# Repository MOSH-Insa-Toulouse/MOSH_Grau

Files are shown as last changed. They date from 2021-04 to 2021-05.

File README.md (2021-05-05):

# MOSH_Grau
# Projet capteur

## SOMMAIRE 
* 1 [Description du projet](#description)
* 2 [Shield](#paragraph2)
* 3 [Arduino](#paragraph3)
* 4 [APK](#paragraph4)  
* 5 [Banc de test](#paragraph5)
* 6 [Idées d'amélioration et de développement](#paragraph6)

   La plupart des iformations se trouvent dans la datasheet.

--------- 
## Description du projet 

Ce projet est réalisé dans le cadre de la formation en ingénierie physique de l'INSA Toulouse. Il vise à introduire le développement de technologies performantes, transportables et à moindre coût. 
Ce projet aborde de nombreuses notions : la physique des systèmes granulaires, l'électroniqe analogique, Arduino Uno, la réalisation d'un PCB, le développement d'APK, la conception d'un banc de test et la réalisation d'une datasheet.

*Objectif* : Développer une jauge de contrainte lowtech, carctérisée et documentée. 

*Description du capteur* : Le capteur est une feuille de papier sur laquelle est déposée une fine couche de graphite. Le graphite déposée peut être vu comme un film conducteur constitué de réseaux de percolation. La déformation du papier se répercute sur les réseaux de percolation et donc sur la conductivité du film de graphite. La déformation du papier est proportionnelle à la variation de conductivité du film de graphite[¹]. Afin d'avoir une mesure de meilleure qualité,et en raison des valeurs de résistance du capteur treès élevées, le signal est conditionné par un circuit analogique comprenant un amplificateur transimpédance et différents filtres. Un écran OLED piloté par un encodeur rotatoire permet d'étendre les fonctionnalités du capteur. Une application Android a également été développée pour faciliter l'utilisation du capteur, même si le capteur se suffit à lui même. L'application et le capteur communique via un module bluetooth. Le shield comprenant tous les composants électroniques s'enfiche sur une carte Arduino Uno.

*Livrables* : 

1. Shield : comprend un amplificateur transimpédance, différents étages de filtrage, un module bluetooth (HC-05), un écran OLED (SSD1306) et un encodeur rotatoire (KY-040). La résistance R2 peut être changée facilement afin d'adapter le gain de l'amplificateur en fonction de la résistance du capteur. 
2. Code Arduino : permet de piloter l'encodeur rotatoire et l'écran OLED. Un menu s'affiche à l'écran avec 3 fonctionnailités principales:
- choix de R2
- choix de l'affichage de différentes mesures en temps réel : soit la tension à la sortie de A0 (ADC sur 10 bits), soit la déformation longitudinale du capteur, ou bien la résistance du capteur. 
- Mesure de contrainte au niveau de la jauge de déformation en fonction du matériaux choisi.
- Calibration du capteur (sensibilité).

Gère les flux de données entre l'APK et le microcontrôleur via le module BT. Permet également d'effectuer les différents traitements de données, comme le calcul de la déformation longitudinale en fonction de la déflection ou encore le calcule de contrainte en fonction de la déformation et d'un certain matériau (module de Young). 

3. APK : Affichage en temps réel  de la tension à la sortie de A0 (ADC sur 10 bits) et tracé du graphe correspondant, affichage de la résistance du capteur, et affichage et modification de la valeur de R2. Un fonctionnalité permet de faire la moyenne des mesures sur 5 secondes. 

[¹]: https://www.nature.com/articles/srep03812

--------- 
## Banc de test 

### Description du banc de test ###

La solution choisie afin de tester et caractériser les capteurs est l'application d'une déflection en compression ou en traction. 

- Déflection en compression : on fixe le capteur au niveau de la partie la plus large, et on applique une déflection contrôlable et mesurable (par exemple avec une règle), perpendiculairement vers le haut (avec la couche de graphite sur la face supérieure du papier) et à l'extrèmité de la jauge pour qu'elle se replie sur elle-même. 
- Déflection en traction : idem qu'en compression mais avec une délection provoquée par une froce dirigée vers le bas (avec la couche de graphite sur la face supérieure du papier). Plus difficile à mettre en oeuvre pour des raisons pratiques, notamment pour mesurer la déflection correctement. On peut alors s'aider de poids que l'on suspend à l'extrémité de la jauge. 

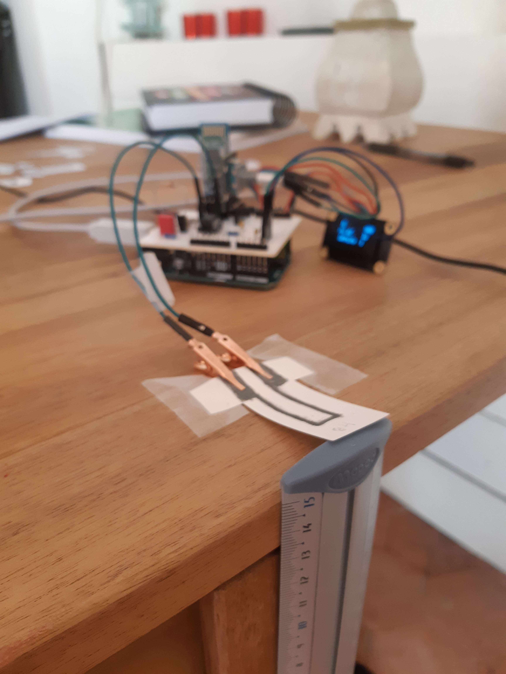
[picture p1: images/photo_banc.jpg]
 
 
 On mesure ainsi la variation de résistance relative en fonction de la déflection. En considérant notre capteur comme une poutre, avec de petites déformation nous pouvons alor remonter à la déformation logitudinale du capteur et calculer son facteur de jauge. Il est important que les prises de contact soient immobiles tout au long de la mesure pour ne pas fausser celle-ci. 
 Il faut également toucher le moins possible la couche de graphite du capteur pour ne pas biaiser les mesures.
 Pour effectuer nos mesures, noud avons moyenné chaque point sur 5 secondes à une fréquence dacquisition de 5Hz. L'incertitude de chaque mesure correspond à l'écart type de l'ensemble des échantillons correspondants à la mesure (voir APK).
 La défelction maximale appliquée est de 2 cm, au delà la déformation du capteur devient trop importante et il se peut que celui-ci se retrouve déformé de manière irréversible. 

**Paramètres étudiés :**

*Paramètres contrôlables :*

1. Type de papier : 
- Papier canson, 180 g/m², épaiseur : 0,21mm
- Feuille A4 de bureau standard, 80 g/m², épaisseur : 0,08mm,
- Fiche Bristol, 205 g/m², épaisseur : 0,22mm

2. Type de crayon : De 4H à 4B
3. Forme de la jauge, notamment la surface de la couche de graphite, la longueur du motif de graphite etc... 
4. Influence de la résistance nominale
5. Influence de R2

*Paramètres non contrôlables :*

1. Formation des réseaux de percolation
2. Epaisseur de la couche de graphite
3. Homogénéité de la couche de graphite

### Influence de R2 sur la mesure ###

La résistance R2 permet d'adapter le gain de l'amplificateur. Il permet notamment de déterminer la plage de résistance mesurable : 

###Idées d'amélioration et de développement 

- Réfléchir à un moyen de déposer le graphite de manière plus homogène
- Continuer à étudier les différents paramètre : dimensions de la jauge de graphite, dimensions du motif de graphite
- Réfléchir à une prise de contact plus appropriée, avec des électrodes fixes
- Continuer à prendre des mesures pour préciser ou réfuter la relation entre la résistance nominale et le facteur de jauge
- Faire les mesures en compression
- Automatiser le banc de test, en fixant tout simplement un fil au bout de la jauge, avec l'autre bout du fil accroché à un servomoteur. L'angle de rotation du servo-moteur est directement relié à la déflection de la jauge. 
- Optimiser le code de l'APK, et de l'Arduino, ajout de nouvelles fonctionnalités

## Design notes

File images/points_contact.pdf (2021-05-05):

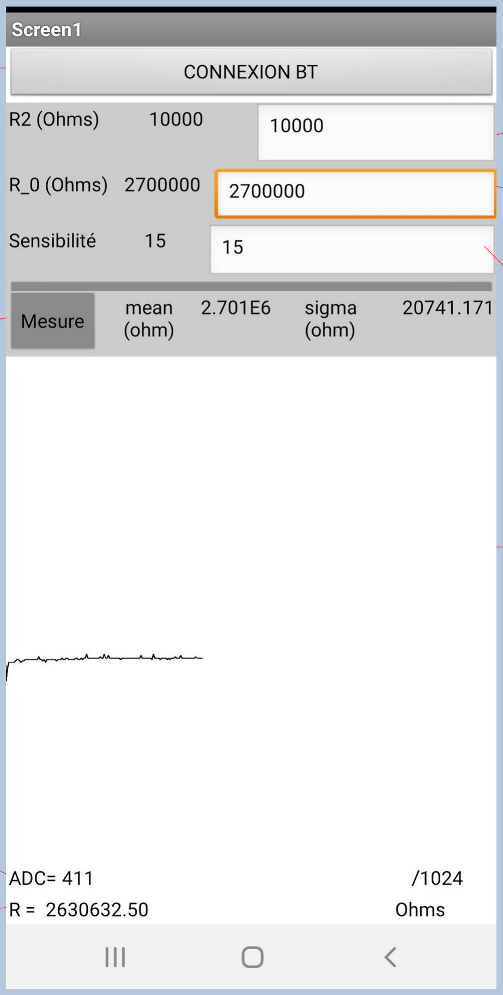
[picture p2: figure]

Bouton permettant
de se connecter au
module Bluetooth

Affichage en temps
réel de la valeur de
la résistance du
capteur en ohm.

Affichage en temps
réel de la valeur de
la tension en ADC
(sur 10 bits) à la
sortie du
conditionneur.

Faire une mesure
sur 5 secondes, la
moyenne et l’écarttype sont ensuite
calculés et
affichés .

Saisie de la
résistance de
calibration du
conditionneur en
ohm.

Saisie de la
résistance
nominale du
capteur en ohm.
Cette valeur peut
être mesurée avec
le bouton
« Mesure » .

Sensibilité du
capteur (Facteur
de jauge)

Tracé en temps
réel de l’évolution
de la tension (ADC)
à la sortie du
conditionneur en
fonction du temps.

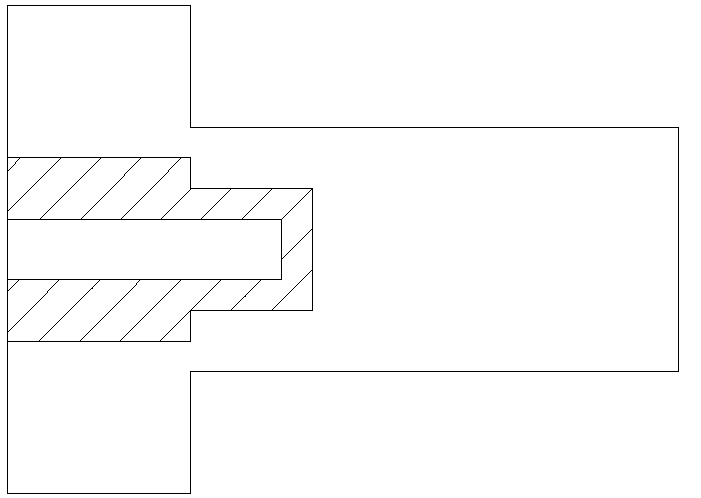
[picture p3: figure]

12

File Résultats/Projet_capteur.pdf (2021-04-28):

# Projet capteur

### victor.grau93

## April 2021

# 1 Introduction

Rapport et résultats projet capteur INSA 4GP

# 2 Inuence de la résistance de calibration (R2)

La résistance R2 permet d’adapter le gain de l’amplicateur. De plus, elle détermine la plage de résistance mesurable :

# valR = (1 + (R3/Rcal)) ∗ R1 ∗ Vcc/V − R1 − R5

Avec V allant de 0 à 5V, donc sur 10 bits, la plus petite valeur de tension est 0,004 V (1 ADC).

Il est aussi important d’avoir en tête la variation de la valeur de la résistance en fonction de la valeur de la tension sur

la pin A0. En eet, on voit avec la gure 2 que si nous sommes aux alentours d’une résistance très élevée, correspondant

à une valeur de tension inférieure à 150 ADC, alors la variation de la tension en fonction de la variation de la résistance

du capteur est très faible. Ce qui rend les mesures compliquées. Inversement, nous pouvons voir qu’à partir d’une tension

de 400 ADC une petite variation de résistance entraîne une importante variation de tension ce qui rend les mesures plus

simples.

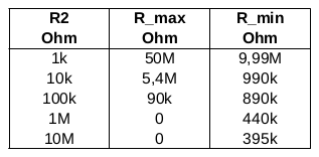
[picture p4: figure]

Figure 1 – Gamme de mesure de la résistance en fonction de la résistance de calibration R2

1

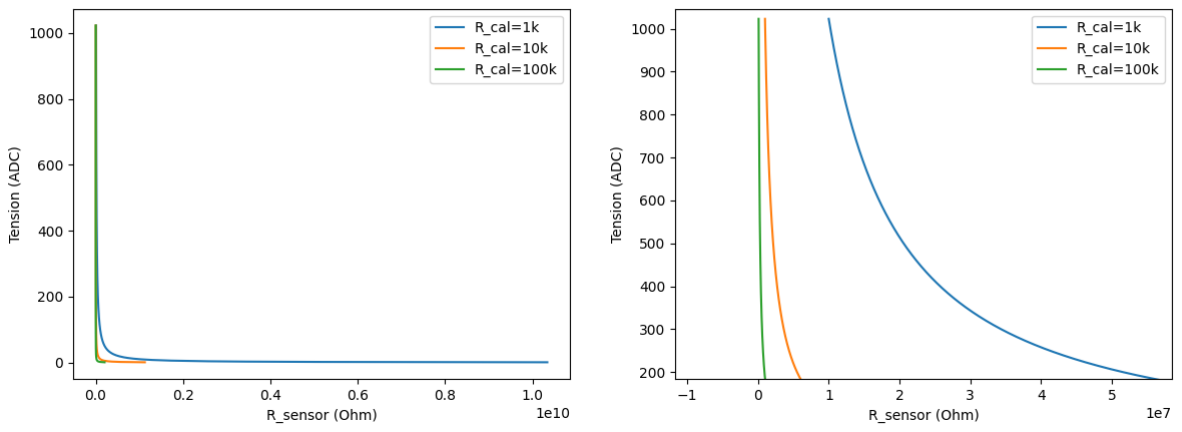
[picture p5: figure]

Figure 2 – Légende | Figure 3 – Légende

2

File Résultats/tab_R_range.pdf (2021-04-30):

Feuille1

R2 Ohm | R_max Ohm
1k 10k 100k 1M 10M | 50M 5,4M 90k 0 0
Papier standard (80 g/m²) | Papier canson 180g/m²
HB
B
Déflection (cm) | R (Mohm)
0,00 0,20 0,40 0,60 0,80 1,00 1,20 1,40 1,60 2,00 | 1,9170 1,9100 1,9010 1,8830 1,8710 1,8590 1,8480 1,8490 1,8370 1,8270

Feuille1

R_min
Ohm
9,99M
990k
890k
440k
395k

Fiche Bristol 205 g/m² Forme de la jauge

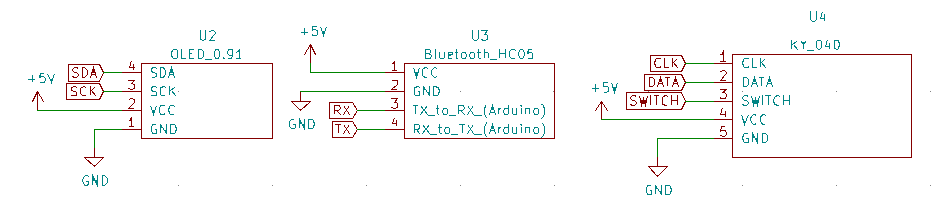
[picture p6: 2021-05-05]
images/cond2.png

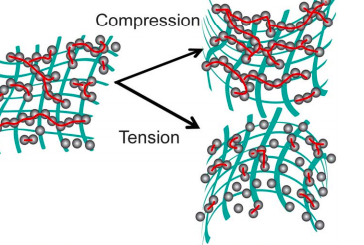
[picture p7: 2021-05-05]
images/percol.png

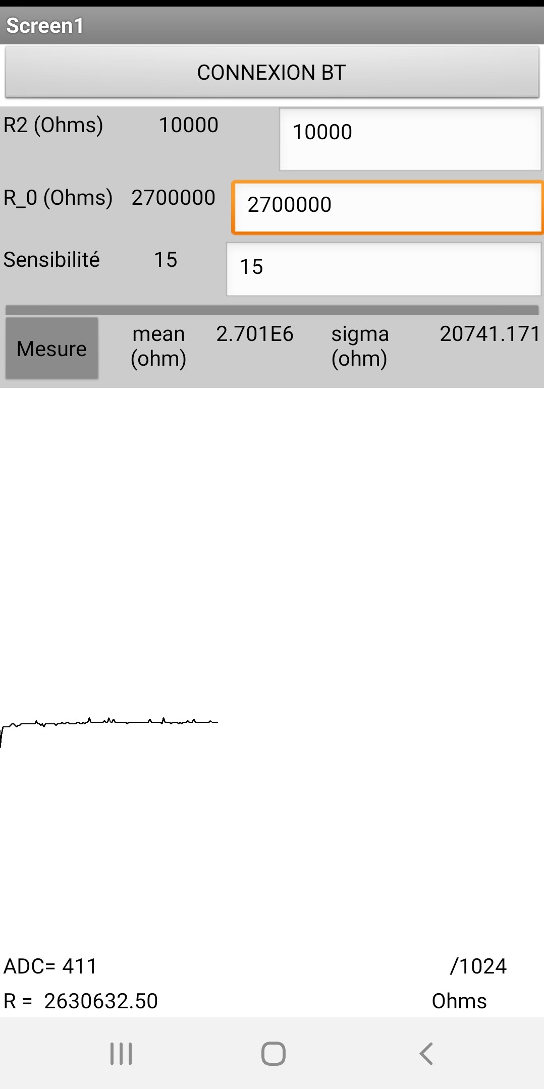
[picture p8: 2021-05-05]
images/photo_APK.jpg

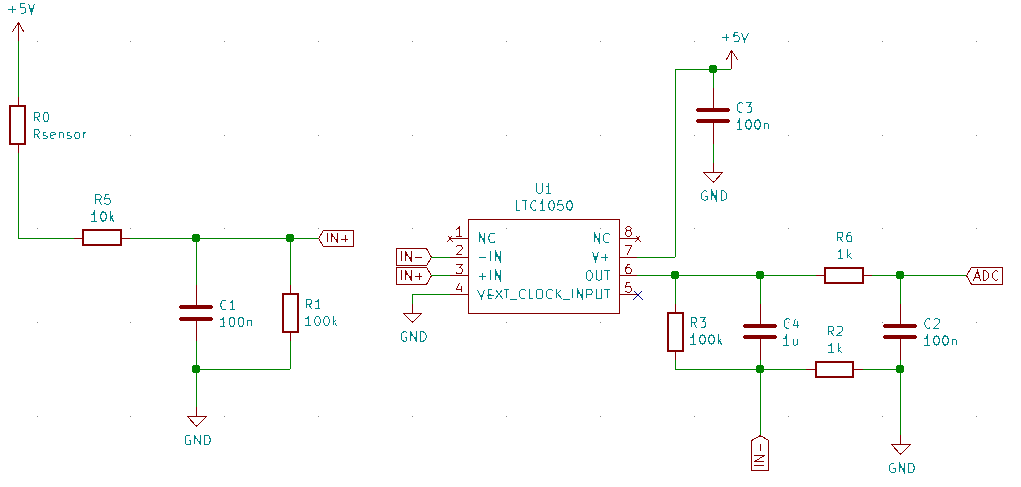
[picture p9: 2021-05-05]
images/cond1.png

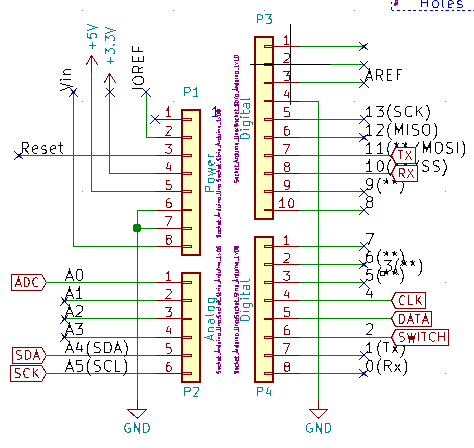
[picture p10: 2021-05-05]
images/pins_arduino.png

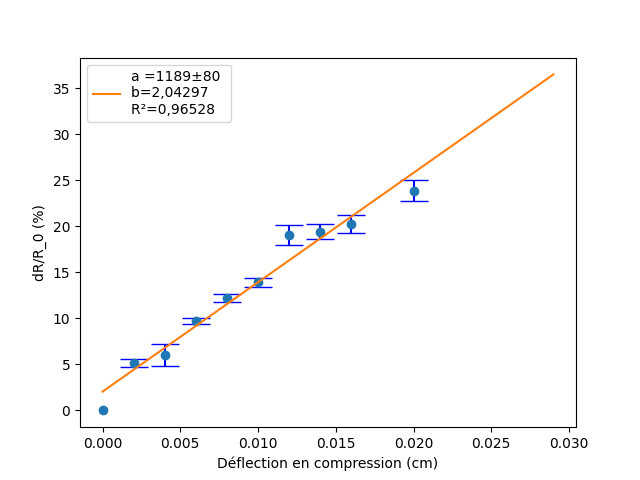
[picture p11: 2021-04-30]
Résultats/graph_205g_4H_comp.png

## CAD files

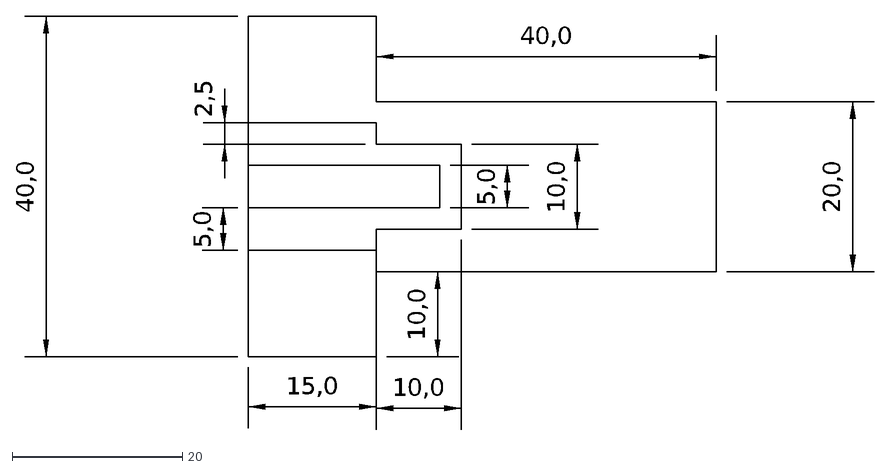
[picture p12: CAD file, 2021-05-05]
esquisses_jauges/#esquisse_jauge.dxf
15,0
10,0
40,0
20,0
5,0
2,5

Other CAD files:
esquisses_jauges/esquisse_jauge.dxf

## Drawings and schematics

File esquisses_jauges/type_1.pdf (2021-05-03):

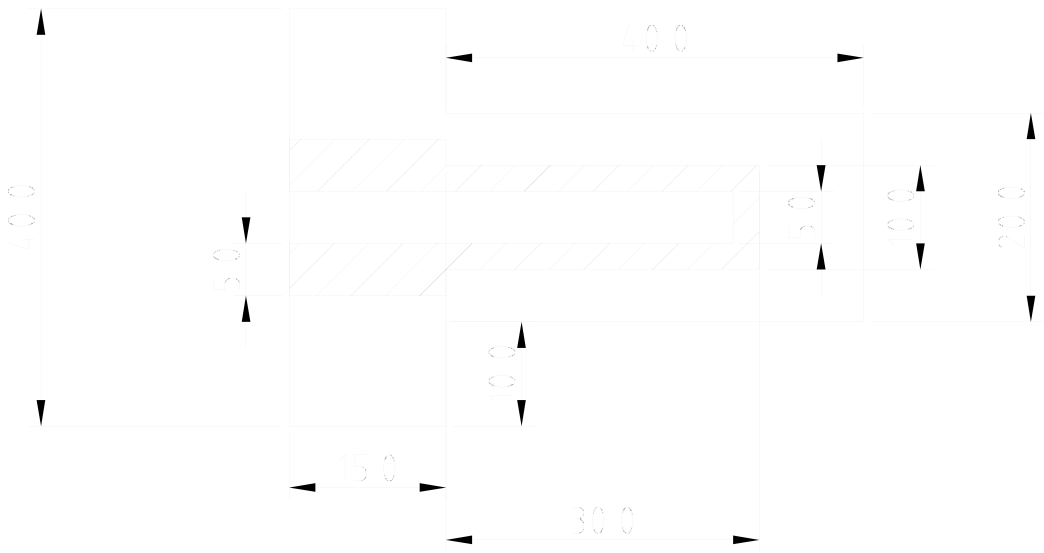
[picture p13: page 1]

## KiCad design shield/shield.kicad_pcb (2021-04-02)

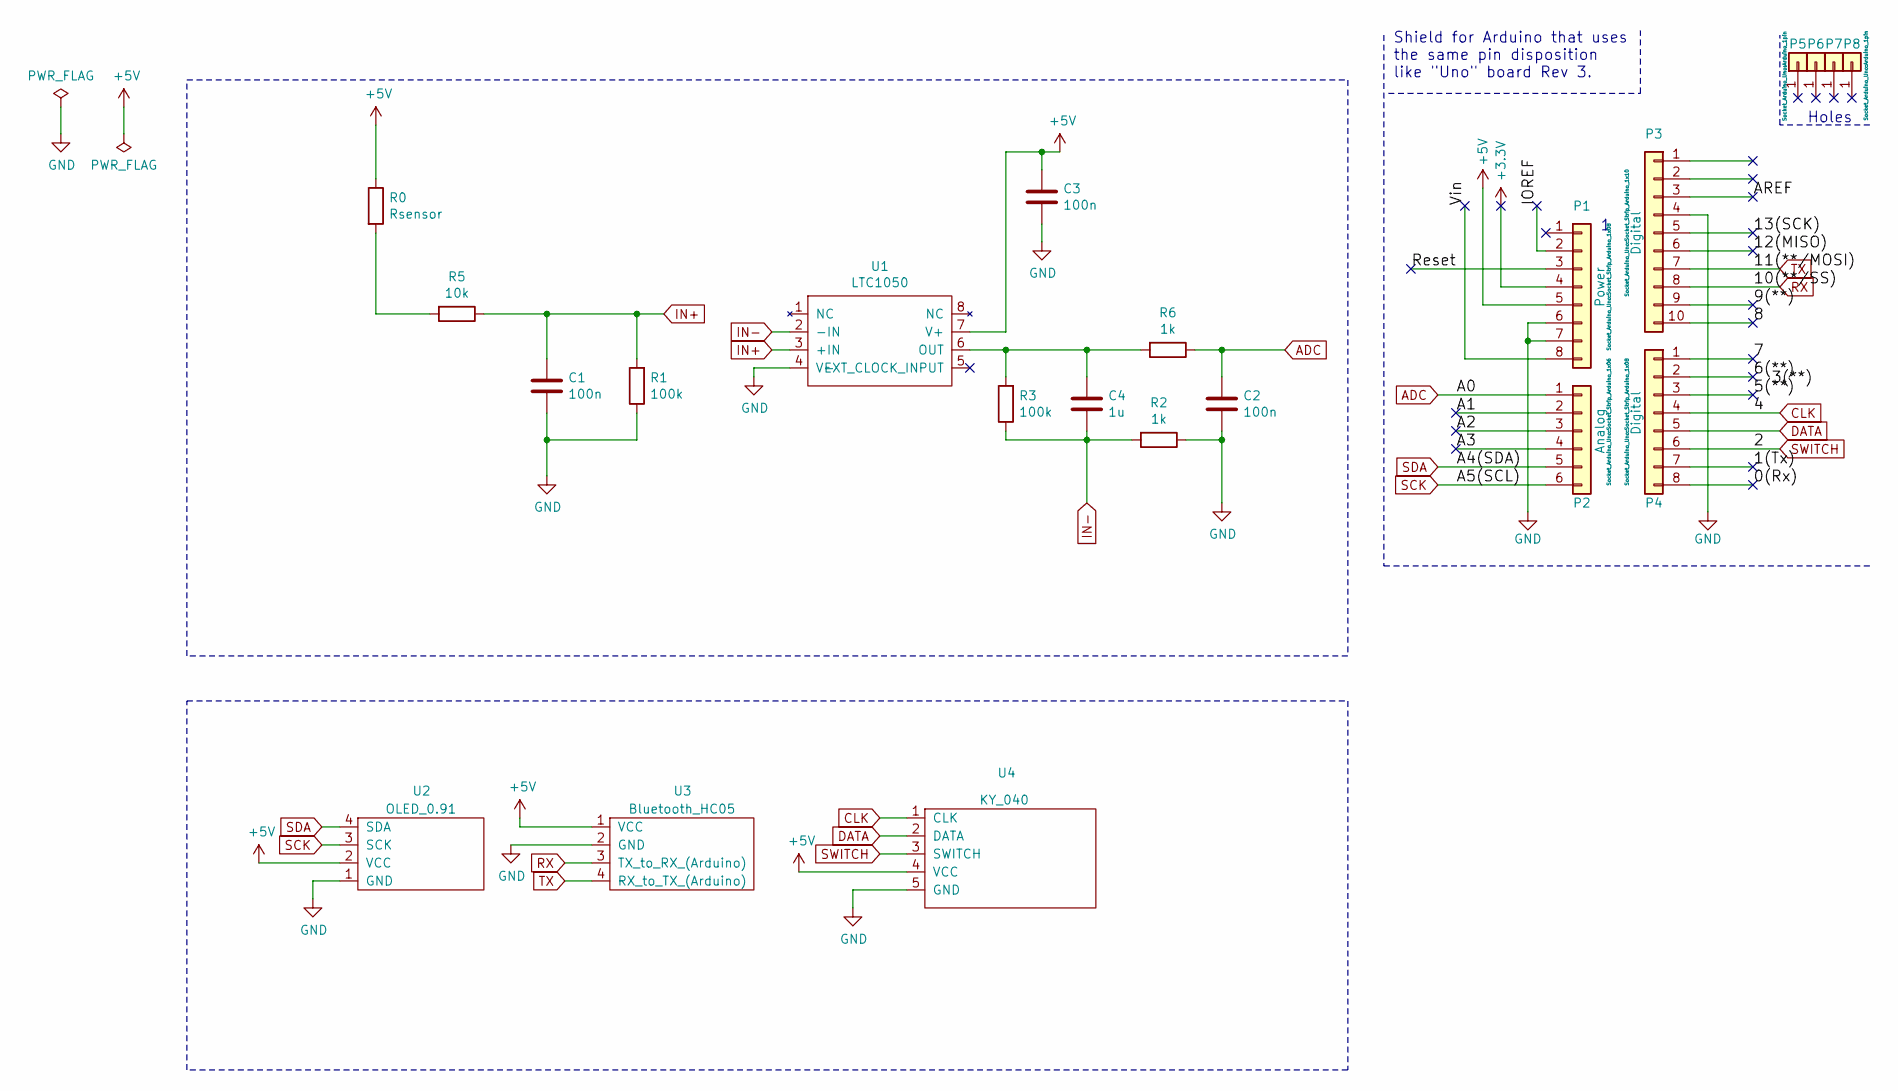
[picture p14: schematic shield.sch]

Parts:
C1, C2, C3: 100n; C_Disc_D5.1mm_W3.2mm_P5.00mm
C4: 1u; C_Disc_D5.1mm_W3.2mm_P5.00mm
P1: Power; Socket_Strip_Arduino_1x08
P2: Analog; Socket_Strip_Arduino_1x06
P3: Digital; Socket_Strip_Arduino_1x10
P4: Digital; Socket_Strip_Arduino_1x08
P5, P6, P7, P8: CONN_01X01; Arduino_1pin
R0: Rsensor; R_Axial_DIN0207_L6.3mm_D2.5mm_P10.16mm_Horizontal
R1, R3: 100k; R_Axial_DIN0207_L6.3mm_D2.5mm_P10.16mm_Horizontal
R2, R6: 1k; R_Axial_DIN0207_L6.3mm_D2.5mm_P10.16mm_Horizontal
R5: 10k; R_Axial_DIN0207_L6.3mm_D2.5mm_P10.16mm_Horizontal
U1: LTC1050; emp_LTC_1050
U2: OLED_0.91; emp_bluetooth_HC05
U3: Bluetooth_HC05; emp_bluetooth_HC05
U4: KY_040

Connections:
+3V3: P1.4
+5V: C3.1, P1.5, R0.1, U1.7 (V+), U2.2 (VCC), U3.1 (VCC), U4.4 (VCC)
/0(Rx): P4.8
/1(Tx): P4.7
/5(**): P4.3
/6(**): P4.2
/7: P4.1
/8: P3.10
/9(**): P3.9
/12(MISO): P3.6
/13(SCK): P3.5
/A1: P2.2
/A2: P2.3
/A3: P2.4
/AREF: P3.3
/IOREF: P1.2
/Reset: P1.3
/Vin: P1.8
ADC: C2.1, P2.1, R6.1
CLK: P4.4, U4.1 (CLK)
DATA: P4.5, U4.2 (DATA)
GND: C1.2, C2.2, C3.2, P1.6, P1.7, P3.4, R1.1, R2.1, U1.4 (V-), U2.1 (GND), U3.2 (GND), U4.5 (GND)
IN+: C1.1, R1.2, R5.1, U1.3 (+IN)
IN-: C4.2, R2.2, R3.1, U1.2 (-IN)
unnamed: C4.1, R3.2, R6.2, U1.6 (OUT)
unnamed: R0.2, R5.2
RX: P3.8, U3.3 (TX_to_RX_(Arduino))
SCK: P2.6, U2.3 (SCK)
SDA: P2.5, U2.4 (SDA)
SWITCH: P4.6, U4.3 (SWITCH)
TX: P3.7, U3.4 (RX_to_TX_(Arduino))

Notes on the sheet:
Holes
Shield for Arduino that uses the same pin disposition like "Uno" board Rev 3.

Board: 2 copper layers, 22 parts (0 on the bottom side), 14 nets, no tracks yet.

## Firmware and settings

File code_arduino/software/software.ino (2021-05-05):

//###################### Libraries import #############

#include <SoftwareSerial.h>
#include <stdio.h>
#include <stdlib.h>
#include<SPI.h>
#include<Wire.h>
#include<Adafruit_GFX.h>
#include<Adafruit_SSD1306.h>

//################## constant BT ##################
#define rxpin 10
#define txpin 11
#define baudrate 9600
SoftwareSerial BT_serial (rxpin, txpin);


//################ constant OLED ############
#define OLED_RESET -1
#define DELAY 1000

//############# constant rotatory encoder  #########
#define encoder0PinA 3 //clk
#define encoder0PinB 4 // DT
#define Switch 2 //switch

Adafruit_SSD1306 display(OLED_RESET);



int ADC_pin = 0;

int data = 0;

//chaîne de caractère décrivant l'état du système : ADC,R2
String system_state="";



//Résistance de calibration
String R2 = "1000";

//Les choix de résistances disponibles sur l'OLED
String tabRes [3]={"100", "1000", "10000"};

//La position de l'incrémentation dans chaque menu
byte countMenus [4]={0,0,0,0};

//byte MainMenuCount = 0;
//byte R2MenuCount = 0;
//byte MeasuresMenuCount = 0;
//byte StressMenuCount = 0;

//Le menu courant
byte currentMenu=3;

//Les différentes mesures
float contrainte = 0;
int tension = 0;
float deformation = 0;
float Rsensor = 0;

//Modules d'Young en GPa de l'acier, Aluminium et Fer
int tabE [3]={210, 69, 196};
int E=0;

String temp="";

//Sensibilité du capteur en %(dR/R_0)/eps. Cette valeur est à déterminer par calibration et à renseigner par l'utilisateur 
//à partir de l'APK
//Avec 205g, HB, l=4cm, e=??
float sensi=15;

//R_0 en ohm
float R_0=7.2*pow(10,6);

//Pour encodeur
int current_pos_enc=0;
int previous_pos_enc=0;

//Timing de la boucle de l'Arduino
const long interval = 500;
unsigned long currentMillis = 0;
unsigned long previousMillis = 0;

//Pour le sens de rotation de l'encodeur
boolean dir = true;
int current_state_pinA = 0;
int previous_state_pinA = 0;

String getValue(String data, char separator, int index)
{
  int found = 0;
  int strIndex[] = {0, -1};
  int maxIndex = data.length()-1;

  for(int i=0; i<=maxIndex && found<=index; i++){
    if(data.charAt(i)==separator || i==maxIndex){
        found++;
        strIndex[0] = strIndex[1]+1;
        strIndex[1] = (i == maxIndex) ? i+1 : i;
    }
  }

  return found>index ? data.substring(strIndex[0], strIndex[1]) : "";
}

//Afficher un texte sur l'écran OLED
void print_oled(String s, int x, int y, uint16_t color, int size_text) {
  display.setTextSize(size_text);
  display.setTextColor(color);
  display.setCursor(x, y);
  display.println(s);
}

//Maj de la position de l'encodeur lorsqu'on le fait tourner
void doEncoder(){
  current_state_pinA = digitalRead(encoder0PinA);
  if (current_state_pinA != previous_state_pinA) {
    if (digitalRead(encoder0PinB != current_state_pinA)) {
    current_pos_enc++;
  }
  else {
    current_pos_enc--;
  }

}
previous_state_pinA = current_state_pinA;
}


//
void doEncoderSwitch(){
  if(currentMenu==3){
  currentMenu=countMenus[3];
  }
  else {
    if(currentMenu==0){
      R2=tabRes[countMenus[0]];
    }
    else if(currentMenu==2){
      E=tabE[countMenus[2]];
    }

    currentMenu=3;
  }
}

//Calcule de la résistance du capteur en fonction de la tension sur la pin analogique 0 et de la résistance de calibration 
float computeRsensor(float Vadc, float Rcal){
  float R=0;
  R=(1+(pow(10, 5)/Rcal))*pow(10,5)*5/((Vadc/1024)*5)-pow(10,5)-pow(10,4);
  return R;
}

//Calcule de la déformation en fonction de al sensibilité (% (dr/R_0) / eps (%))
float computeEps(float R_0, float sensi, float R){
  float dR=((R_0-R)/R_0)*100;
  return (dR/sensi);
}


//Afiichage du menu principal
void mainMenu() {

  //---------------------------------
  print_oled("R2 : ", 10, 0, WHITE, 1);
  print_oled(R2, 90, 0, WHITE, 1);

  print_oled("ADC : ", 10, 10, WHITE, 1);
  print_oled(String(data), 90, 10, WHITE, 1);

  print_oled("Contrainte : ", 10, 20, WHITE, 1);
  print_oled(String(contrainte), 90, 20, WHITE, 1);


  display.setCursor(2, (countMenus[3] * 10));
  display.println(">");

  display.display();
}

//Afiichage du menu du choix de la résistance de calibration 
void R2Menu() {

  //---------------------------------
  print_oled("100", 10, 0, WHITE, 1);

  print_oled("1000", 10, 10, WHITE, 1);

  print_oled("10000", 10, 20, WHITE, 1);

  display.setCursor(2, (countMenus[0] * 10));
  display.println(">");

  display.display();
}

//Affichage du menu des choix de mesures
void MeasuresMenu() {

  //---------------------------------
  print_oled("R : ", 10, 0, WHITE, 1);
  print_oled(String(Rsensor,0), 60, 0, WHITE, 1);

  print_oled("ADC : ", 10, 10, WHITE, 1);
  print_oled(String(data), 60, 10, WHITE, 1);

  print_oled("Def : ", 10, 20, WHITE, 1);
  print_oled(String(deformation, 3), 60, 20, WHITE, 1);

  display.setCursor(2, (countMenus[1] * 10));
  display.println(">");

  display.display();
}

//Affichage du menu du calcule de contraintes
void StressMenu() {

  //---------------------------------
  print_oled("Acier", 10, 0, WHITE, 1);

  print_oled("Aluminium", 10, 10, WHITE, 1);

  print_oled("Fer", 10, 20, WHITE, 1);

  display.setCursor(2, (countMenus[2] * 10));
  display.println(">");

  display.display();
}



void setup() {

  //Pin du bus Serie
  pinMode(rxpin, INPUT);
  pinMode(txpin, OUTPUT);

  //Initialyse Input for rotatory encoder
  pinMode(encoder0PinA, INPUT);
  pinMode(encoder0PinB, INPUT);
  pinMode(Switch, INPUT);

  //turn on pullup resistor
  digitalWrite(encoder0PinA, HIGH);
  digitalWrite(encoder0PinB, HIGH);
  digitalWrite(Switch, HIGH);

  previous_state_pinA = digitalRead(encoder0PinA);


  Serial.begin(baudrate);
  BT_serial.begin(baudrate);

  attachInterrupt(1, doEncoder, RISING);
  attachInterrupt(digitalPinToInterrupt(2), doEncoderSwitch, FALLING);

  //Ecran de démarrage
  display.begin(SSD1306_SWITCHCAPVCC, 0x3c);
  display.display();

  delay(2000);
  display.clearDisplay();

  print_oled("Bonjour !", 64, 16, WHITE, 1);

  display.display();

  delay(3000);

}

void loop() {
  currentMillis = millis();
  //On boucle en fonction de l'interval défini
  if ((currentMillis - previousMillis) >= interval) {

    //Lecture de la valeur de la tension sur la pin analogique 0
    data = analogRead(ADC_pin);

    //Nettoyage des buffers
    BT_serial.flush();
    Rsensor=computeRsensor(data, R2.toInt());
    deformation=computeEps(R_0, sensi, Rsensor);
    contrainte=E*deformation/100;

    //Récupération de l'état du système
    system_state=String(data)+","+String(Rsensor)+","+R2;
    //Etat du système envoyé sur l'APK
    BT_serial.println(system_state);
    //Serial.println(system_state);
    previousMillis=currentMillis;
  }
  if (BT_serial.available()) {
    //Lecture des données envoyées par l'APK (pour l'instant que la résistance de calibration 

    temp=(BT_serial.readString());
    R2=getValue(temp, ',', 0).toInt();
    sensi=getValue(temp, ',', 1).toInt();
    R_0=getValue(temp, ',', 2).toInt();
    Serial.println(R2);
  }

  //Gestion de l'afichage des différents menus
  switch(currentMenu){
    case 0:
      display.clearDisplay();
      R2Menu();
      break;
    case 1:
      display.clearDisplay();
      MeasuresMenu();
      break;
    case 2:
      display.clearDisplay();
      StressMenu();
      break;
    case 3:
      display.clearDisplay();
      mainMenu();
      break;
  }
 
  
  
  if((current_pos_enc-previous_pos_enc) >= 4){

    //MainMenuCount++;
    //MainMenuCount=MainMenuCount%3;
    //previous_pos_enc=current_pos_enc;

    countMenus[currentMenu]++;
    countMenus[currentMenu]=countMenus[currentMenu]%3;
    previous_pos_enc=current_pos_enc;


    
  }
   if((current_pos_enc-previous_pos_enc) <= -4){

    countMenus[currentMenu]--;
    countMenus[currentMenu]=countMenus[currentMenu]%3;
    previous_pos_enc=current_pos_enc;
  }
  
}

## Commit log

2021-04-02 ajout du dossier Projet_Kicad_Victor
    [shield.kicad_pcb, shield.sch]
2021-04-02 commit 02/04/21 test
    [shield.kicad_pcb, shield.sch]
2021-04-05 premier commit du dossier shield
    [shield.kicad_pcb, shield.sch]
2021-04-10 commit organisation des fichiers
2021-04-12 ajout des menus
2021-04-30 commit arduino
2021-05-02 commit code arduino, ajout fonctionnalités 02/05
2021-05-05 commit APK
    [#esquisse_jauge.dxf, esquisse_jauge.dxf]
